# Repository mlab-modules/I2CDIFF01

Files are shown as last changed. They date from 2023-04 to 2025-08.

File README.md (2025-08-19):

# I2CDIFF01 - Differential I²C Transceiver

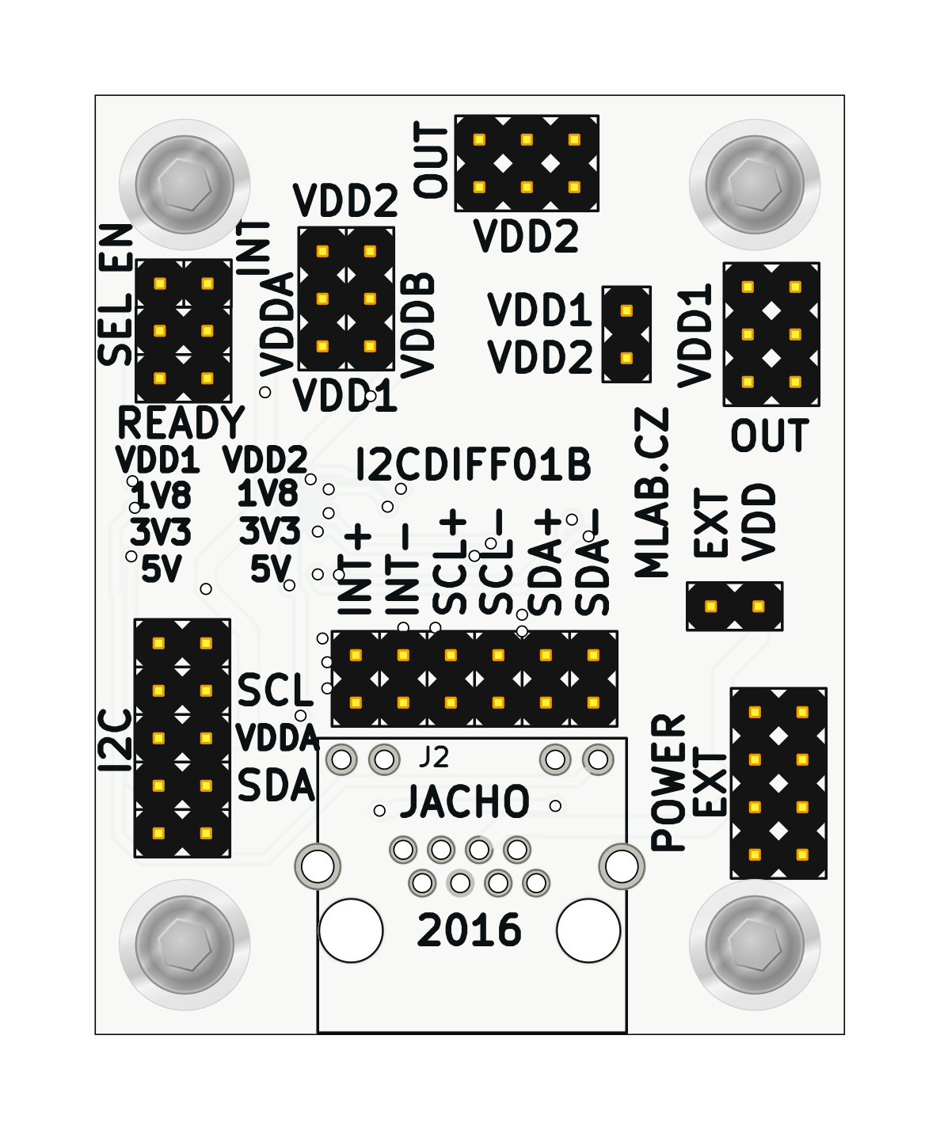
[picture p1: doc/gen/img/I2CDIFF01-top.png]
I2CDIFF01B


Allows long-range I²C communication in harsh environments. In addition to I²C data transfer, the module supports bidirectional interrupt signaling over the same cable.

## Features

* Converts standard I²C signals to differential I²C for robust transmission
* Supports interrupt signal transmission
* Uses PCA9616 buffer for differential I²C communication
* Enables power transmission over RJ45 cable
* Configurable voltage levels using onboard jumpers
* Power regulation with onboard voltage regulators
* RJ45 (Ethernet) cable for differential connection (UTP cable compatible)

## Technical Specifications

| Parameter | Value |
| --- | --- |
| Supply Voltage | Up to 15 V |
| Communication  | I²C, Differential I²C |
| Main IC | PCA9616 |
| Dimensions | 40.1 × 50.3 × 16 mm |

## Power and Voltage Configuration

* **VDDA**: Voltage for single-ended I²C side (selectable 3.3 V or 5 V by jumper; replace regulator for other voltages)
* **VDDB**: Voltage for differential I²C side (recommended 5 V)
* Power is supplied via the RJ45 cable; only one module in the chain should provide power
* Optional jumper on EXT-VDD allows routing of input voltage to internal regulator if below 15 V

## Connector Use

* **RJ45 connector** used for differential I²C transmission and power
* Do not connect the RJ45 cable to standard Ethernet equipment

## Jumpers and Configuration

* Jumpers available to select voltage sources (VDD1 or VDD2) for VDDA and VDDB
* Recommended not to use the SEL jumper when VDDA > 2.2 V
* Voltage levels indicated on PCB; use permanent marker to label used levels

## Typical Use Cases

* Extending I²C bus over longer distances
* Connecting devices across electrically noisy environments
* Applications requiring shared interrupt signaling across modules

## Notes

* Ensure proper termination of differential pairs per PCA9616 datasheet
* Verify jumper settings and supply voltages before powering the module
* Do not mix power sources across RJ45-connected modules

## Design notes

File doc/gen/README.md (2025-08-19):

# PCB

Board size: 40.13x50.29 mm (1.58x1.98 inches)

- This is the size of the rectangle that contains the board
- Thickness: 1.6 mm (63 mils)
- Material: FR4
- Finish: HAL
- Layers: 2
- Copper thickness: 35 µm

Solder mask: TOP / BOTTOM

- Color: Green

Silk screen: TOP / BOTTOM

- Color: White

# Important sizes

Clearance: 0.2 mm (8 mils)

Track width: 0.25 mm (10 mils)

- By design rules: 0.2 mm (8 mils)

Drill: 0.6 mm (24 mils)

- Vias: 0.6 mm (24 mils) [Design: 0.4 mm (16 mils)]
- Pads: 1.0 mm (39 mils)
- The above values are real drill sizes, they add 0.1 mm (4 mils) to plated holes (PTH)

Via: 0.89/0.5 mm (35/20 mils)

- By design rules: 0.7/0.3 mm (28/12 mils)
- Micro via: yes [0.3/0.1 mm (12/4 mils)]
- Buried/blind via: yes
- Total: 29 (thru: 29 buried/blind: 0 micro: 0)

Outer Annular Ring: 0.13 mm (5 mils)

- By design rules: 0.13 mm (5 mils)

Eurocircuits class: 6A
- Using min drill 0.6 mm for an OAR of 0.13 mm

# General stats

Components count: (SMD/THT)

- Top: 0/27 (THT)
- Bottom: 29/0 (SMD)

Defined tracks:

- 0.25 mm (10 mils)
- 0.3 mm (12 mils)
- 0.4 mm (16 mils)
- 0.5 mm (20 mils)
- 0.6 mm (24 mils)
- 0.7 mm (28 mils)
- 0.8 mm (31 mils)
- 0.9 mm (35 mils)

Used tracks:

- 0.25 mm (10 mils) (8) defined: yes
- 0.3 mm (12 mils) (180) defined: yes
- 0.4 mm (16 mils) (56) defined: yes
- 0.5 mm (20 mils) (63) defined: yes
- 0.6 mm (24 mils) (9) defined: yes
- 0.9 mm (35 mils) (84) defined: yes

Defined vias:

Used vias:

- 0.89/0.5 mm (35/20 mils) (Count: 29, Aspect: 1.8 A) defined: no

Holes (excluding vias):

- 0.89 mm (35 mils) (58)
- 0.93 mm (37 mils) (12)
- 1.65 mm (65 mils) (2)
- 3.0 mm (118 mils) (4)
- 3.3 mm (130 mils) (2)

Oval holes:

Drill tools (including vias and computing adjusts and rounding):

- 0.6 mm (24 mils) (29)
- 1.0 mm (39 mils) (58)
- 1.05 mm (41 mils) (12)
- 1.75 mm (69 mils) (2)
- 3.1 mm (122 mils) (4)
- 3.3 mm (130 mils) (2)

Solder paste stats:

Using a paste with 87.75 % alloy, that has an specific gravity for the alloy of 7.4 g/cm³
and 1.0 g/cm³ for the flux. This paste has an specific gravity of  4.15 g/cm³.

The stencil thickness is  0.12 mm.

| Side | Pads with paste | Area [mm²] | Paste [g] |
|---|---|---|---|
| Total  | 82 | 118.29 | 0.59 |

Note: this is just an approximation to the theoretical value. Margins of the solder mask and waste aren't computed.

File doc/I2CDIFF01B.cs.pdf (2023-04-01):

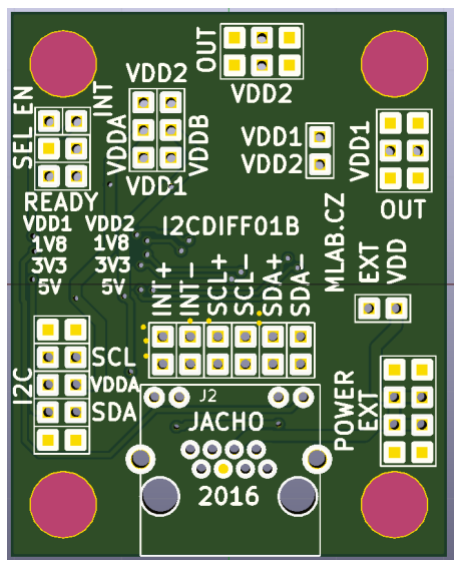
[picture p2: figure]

I2CDIFF01B / 2018-11-05 / jacho / http://www.mlab.cz | 1 / 5
I2CDIFF01B | MLAB

# I2CDIFF01B – převodník I2C / diferenční I2C

Jan Chroust, Jakub Kákona

Převodník umožňuje přenášet I2C signál na delší vzdálenosti i v nepříznivých podmínkách. Tento vzdálený přenos je možný díky převodu klasického I2C na diferenční. Modul umožňuje obousměrné přenášení interruptu. Propojení na straně diferenčního signálu je pomocí kabelu s RJ45 (ethernetový kabel). Modul umožňuje přenášení napájecího napětí mezi dvojicí modulů. Díky dvojici stabilizátorů je možné napětí upravit na běžně používané napěťové

úrovně.

# 1. Technické parametry

Parametr | Hodnota | Poznámka
Napájení | Max 15 V
Rozhraní | I2C, diferenční I2C
Integrovaný obvod | PCA9616
Rozměr | 40,1 x 50,3 x 16 mm

I2CDIFF01B | MLAB

# 2. Popis konstrukce

## 2.1. Úvodem

Jedná se o převodník s mnoha možnostmi využití. Převodníky je možné vložit mezi jakékoliv zařízení komunikující na I2C a tím umožnit prodloužení vzdálenosti mezi zařízeními. Výhodou modulu je, že není potřeba žádné změny kódu v zařízení.

Propojování převodníků je možné realizovat pomocí standardního ethernetového kabelu s konektorem RJ45. Struktura propojení může být různá dle požadavku aplikace (hvězdicová topologie, stromová topologie…).

I když modul obsahuje konektor RJ45, tak není možné tento modul zapojit do jakýchkoliv jiných zařízení, krom tohoto modulu!!!

Napájení modulu je vedeno v datovém kabelu. Modul je možné napájet maximálním napětím 15 V. Napětí je omezeno stabilizátory. Pokud by bylo potřeba přenášet kabelem napětí větší, tak je potřeba od tohoto napětí odpojit napájení modulu. Následně je možné napětí externím měničem snížit a zpátky přivést pro napájení modulu.

Pokud je napájení po kabelu menší než 15 V je možné pomocí jumperu na EXT-VDD přivést toto napětí na vstup stabilizátoru.

Modul umožňuje pomocí jumperů volbu napěťové úrovně pro signály na obou stranách. Na straně diferenčního I2C je doporučena úroveň 5V (vyšší napětí obvod neumožňuje). Na straně I2C je možné si standardně volit mezi 3,3 V nebo 5 V. Při potřebě nižšího napětí je potřeba modul osadit jiným stabilizátorem.

VDDA je napětí pro stranu I2C. VDDB je napětí pro diferenční I2C.

Napětí, které je připojeno na VDDA, nebo VDDB se volí pomocí jumperů. Napětí je možné volit mezi VDD1 a VDD2. Tyto hodnoty jsou dány osazenými stabilizátory. Aktuální napětí je vždy zobrazeno na plošném spoji. Ostatní úrovně napětí se zaškrtávají nesmazatelným fixem.

Pokud je VDDA zvoleno větší než 2,2 V, tak není potřeba umísťovat na pozici SEL jumper.

Napájecí hřebínek POWER EXT je propojen s napájecím párem vodičů na konektoru RJ45. Na jedné straně proto tento hřebínek slouží pro přivedení napětí, které je přes kabel přivedeno na konektor POWER EXT druhého převodníku, kde tento hřebínek slouží jako výstupní. Není proto možné připojit na tyto konektory na obou stranách napájení a propojit je mezi sebou ethernetovým kabelem. Při propojení více převodníků mezi sebou může být přivedeno napětí pouze na jeden hřebínek na ostatních převodníkách se tento hřebínek chová jako výstupní.

I2CDIFF01B | MLAB

# 3. Zapojení modulu

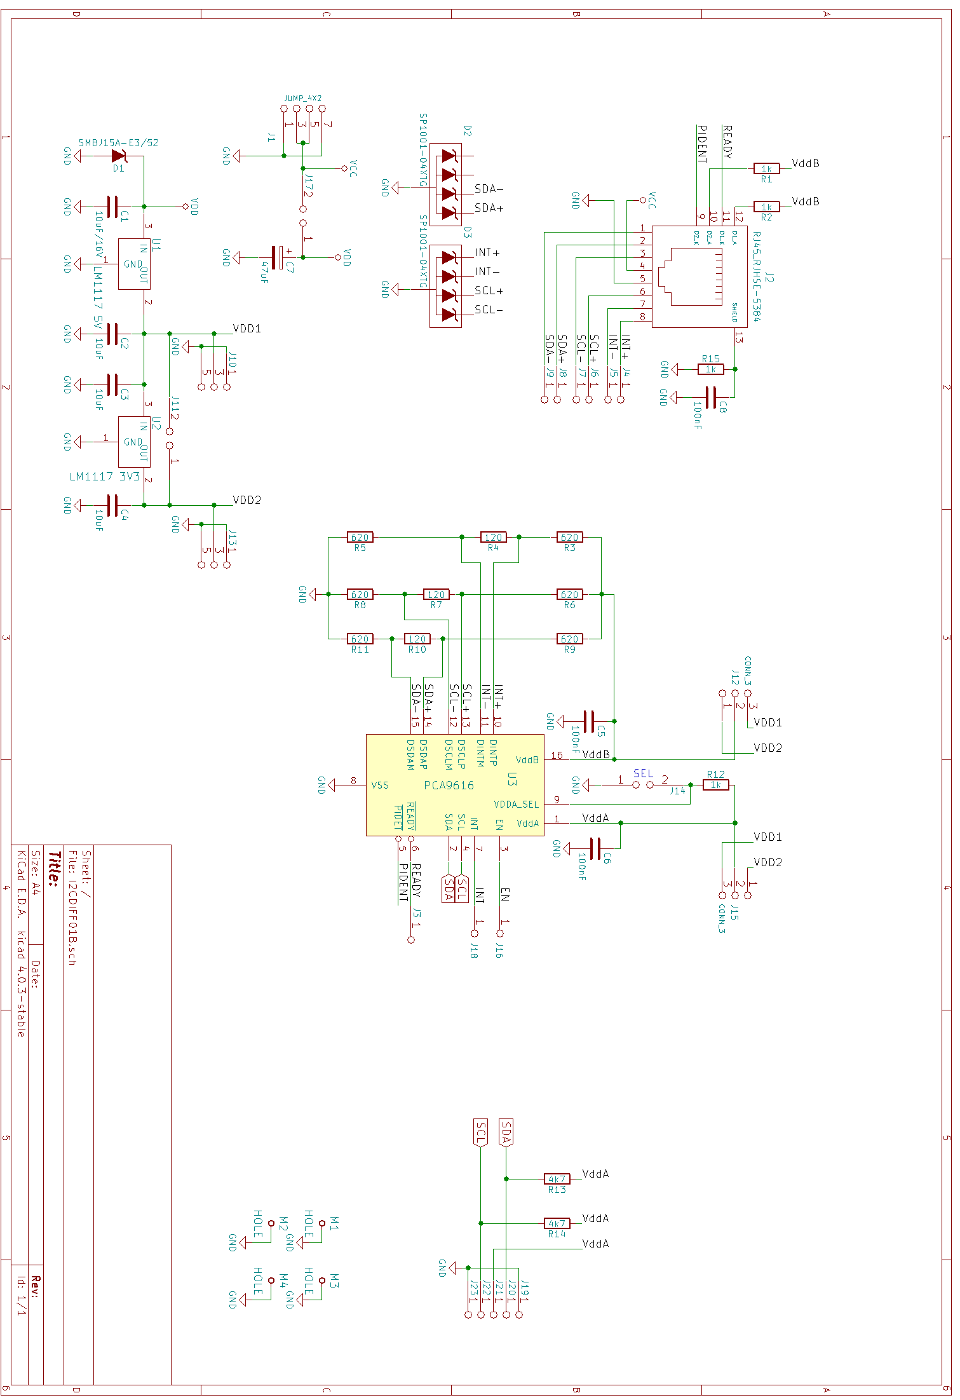
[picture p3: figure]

I2CDIFF01B | MLAB

# 4. Osazení a oživení

## 4.1. Osazení

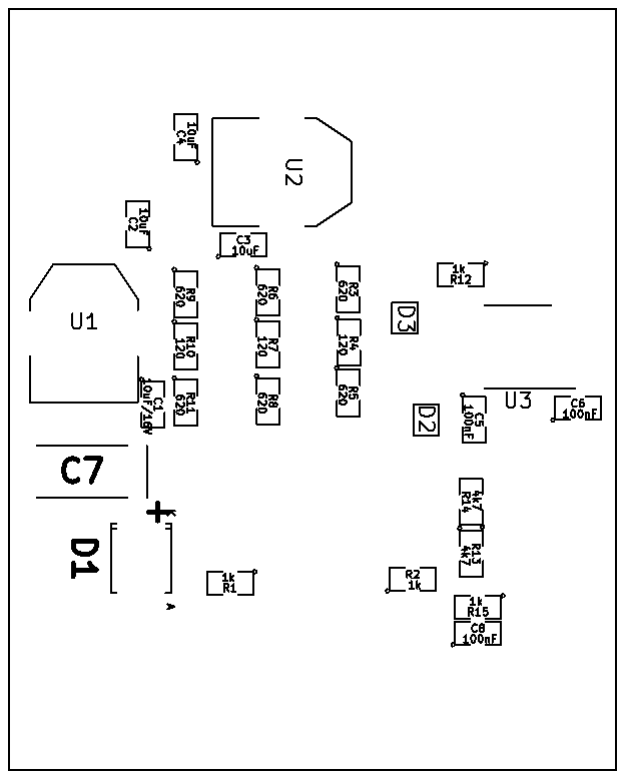
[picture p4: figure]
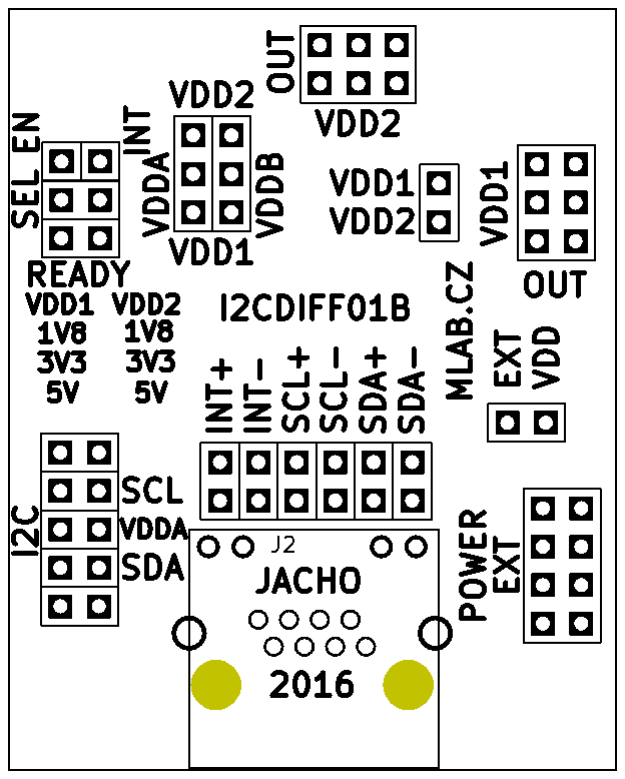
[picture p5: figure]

I2CDIFF01B | MLAB

## 4.2. Seznam součástek

Označení | Typ | Pouzdro | Počet
J2 | RJ45_RJHSE-5384 | RJHSE-5384(RJ45) | 1
J1 | JUMP_4X2 | Straight_2x04 | 1
C1 | 10uF/16V | SMD-0805 | 1
C2,C3,C4 | 10uF | SMD-0805 | 3
C6,C5 | 100nF | SMD-0805 | 2
J4,J5,J6,J7,J8,J9 | JUMP_2x1 | Straight_2x01 | 6
J10,J13 | JUMP_3X2 | Straight_2x03 | 2
J11,J14,J17 | JUMP2_2x1 | Straight_2x01 | 3
J12,J15 | CONN_3 | Straight_1x03 | 2
J19,J20,J21,J22,J23,J3 | JUMP_2x1 | Straight_1x02 | 6
M1,M2,M3,M4 | HOLE | MountingHole_3mm | 4
R1,R2,R12 | 1k | SMD-0805 | 3
R3,R5,R6,R8,R9,R11 | 620 | SMD-0805 | 6
R4,R7,R10 | 120 | SMD-0805 | 3
R14,R13 | 4k7 | SMD-0805 | 2
U1 | LM1117 5V | SOT-223 | 1
U2 | LM1117 3V3 | SOT-223 | 1
U3 | PCA9616 | TSSOP-16_4.4x5mm_Pitch0.65mm | 1
C7 | 47uF | TantalC_SizeC_Reflow | 1
D2,D3 | SP1001-04XTG | SOT-553 | 2
C8 | 100nF | SMD-0805 | 1
R15 | 1k | SMD-0805 | 1
J18,J16 | CONN1_1 | Straight_1x01 | 2
D1 | SMBJ15A-E3/52 | Diode-SMB_Standard | 1

Jumper: VDDA-VDD2, VDDB-VDD1, EXT-VDD

Začernit nevyužitá napětí stabilizátorů

## 4.3. Oživení

Zkontrolovat zkraty na napájení

Ověřit úrovně napětí za stabilizátory

Postup pro ověření funkčnosti:
-propojit dva I2CDIFF pomocí ethernetového kabelu
-k jednomu I2CDIFF připojit I2C senzor, který má knihovnu v pyMLAB
-ke druhému I2CDIFF připojit převodník USBI2C
-jeden I2CDIFF je potřeba napájet 12V
-následně stačí připojit USB kabel do počítače vyvedený z USBI2C a spustit program v pyMLABu.

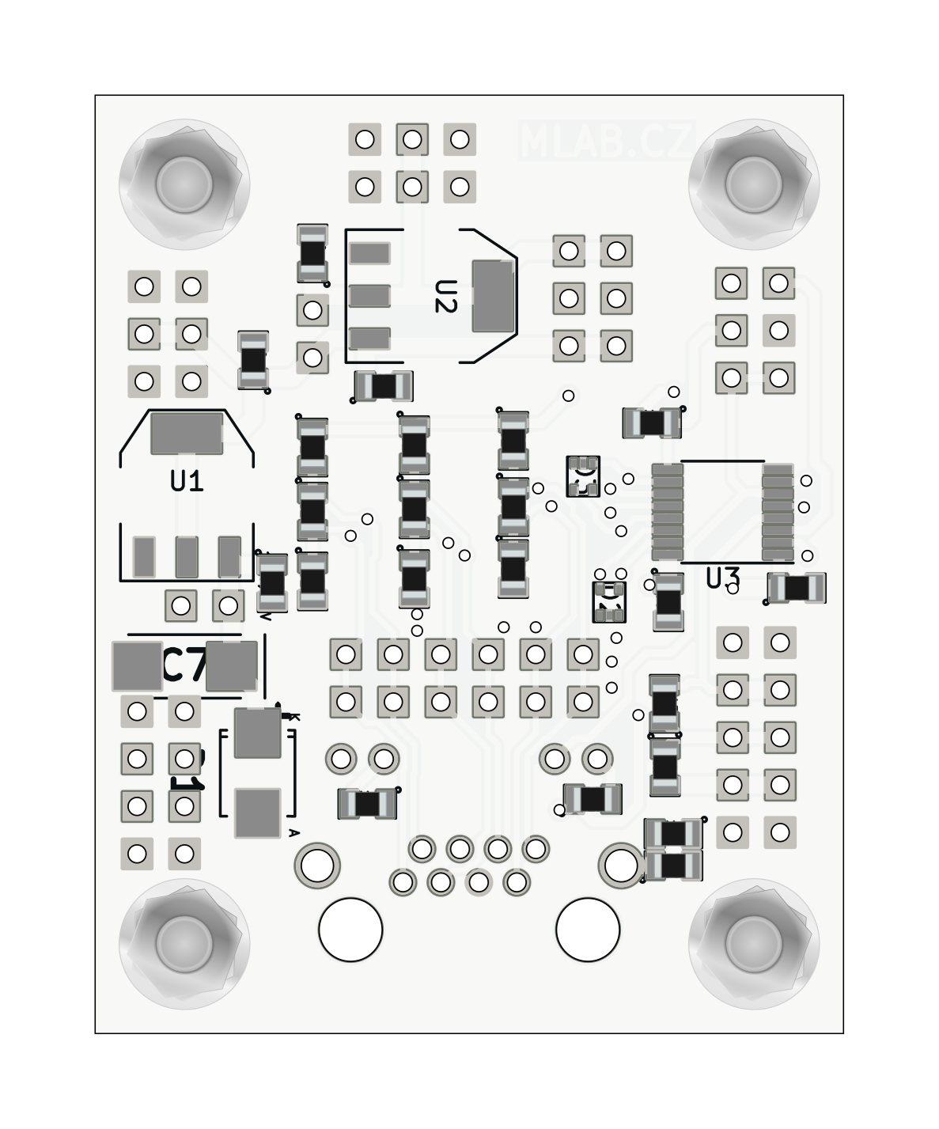
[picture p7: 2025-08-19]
doc/gen/img/I2CDIFF01-bottom.png

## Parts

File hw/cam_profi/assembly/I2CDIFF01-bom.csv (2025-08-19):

Component | Description | Part | References | Value | Footprint | Quantity Per PCB | Datasheet
1 |  | C_9 | C5 | 100nF | SMD-0805 | 1
2 |  | C_8 | C6 | 100nF | SMD-0805 | 1
3 |  | C_10 | C8 | 100nF | SMD-0805 | 1
4 |  | C_12 | C2 | 10uF | SMD-0805 | 1
5 |  | C_13 | C3 | 10uF | SMD-0805 | 1
6 |  | C_14 | C4 | 10uF | SMD-0805 | 1
7 |  | CP_2 | C7 | 47uF | TantalC_SizeC_Reflow | 1
8 |  | C_11 | C1 | 10uF/16V | SMD-0805 | 1
9 |  | D_ZENER_2 | D1 | SMBJ15A-E3/52 | Diode-SMB_Standard | 1
10 |  | D_4xZENER_3 | D2 | SP1001-04XTG | SOT-553 | 1
11 |  | D_4xZENER_4 | D3 | SP1001-04XTG | SOT-553 | 1
12 |  | CONN1_1_3 | J16 | CONN1_1 | Straight_1x01 | 1
13 |  | CONN1_1_4 | J18 | CONN1_1 | Straight_1x01 | 1
14 |  | CONN_3_4 | J12 | CONN_3 | Straight_1x03 | 1
15 |  | CONN_3_3 | J15 | CONN_3 | Straight_1x03 | 1
16 |  | JUMP2_2x1_6 | J11 | JUMP2_2x1 | Straight_2x01 | 1
17 |  | JUMP2_2x1_4 | J14 | JUMP2_2x1 | Straight_2x01 | 1
18 |  | JUMP2_2x1_5 | J17 | JUMP2_2x1 | Straight_2x01 | 1
19 |  | JUMP_2x1_17 | J19 | JUMP_2x1 | Straight_1x02 | 1
20 |  | JUMP_2x1_15 | J20 | JUMP_2x1 | Straight_1x02 | 1
21 |  | JUMP_2x1_16 | J21 | JUMP_2x1 | Straight_1x02 | 1
22 |  | JUMP_2x1_18 | J22 | JUMP_2x1 | Straight_1x02 | 1
23 |  | JUMP_2x1_14 | J23 | JUMP_2x1 | Straight_1x02 | 1
24 |  | JUMP_2x1_13 | J3 | JUMP_2x1 | Straight_1x02 | 1
25 |  | JUMP_2x1_24 | J4 | JUMP_2x1 | Straight_2x01 | 1
26 |  | JUMP_2x1_19 | J5 | JUMP_2x1 | Straight_2x01 | 1
27 |  | JUMP_2x1_20 | J6 | JUMP_2x1 | Straight_2x01 | 1
28 |  | JUMP_2x1_21 | J7 | JUMP_2x1 | Straight_2x01 | 1
29 |  | JUMP_2x1_22 | J8 | JUMP_2x1 | Straight_2x01 | 1
30 |  | JUMP_2x1_23 | J9 | JUMP_2x1 | Straight_2x01 | 1
31 |  | JUMP_3X2_4 | J10 | JUMP_3X2 | Straight_2x03 | 1
32 |  | JUMP_3X2_3 | J13 | JUMP_3X2 | Straight_2x03 | 1
33 |  | JUMP_4X2_2 | J1 | JUMP_4X2 | Straight_2x04 | 1
34 |  | RJ45_RJHSE-5384_2 | J2 | RJ45_RJHSE-5384 | RJHSE-5384(RJ45) | 1
35 |  | R_24 | R10 | 120 | SMD-0805 | 1
36 |  | R_26 | R4 | 120 | SMD-0805 | 1
37 |  | R_21 | R7 | 120 | SMD-0805 | 1
38 |  | R_23 | R11 | 620 | SMD-0805 | 1
39 |  | R_27 | R3 | 620 | SMD-0805 | 1
40 |  | R_25 | R5 | 620 | SMD-0805 | 1
41 |  | R_18 | R6 | 620 | SMD-0805 | 1
42 |  | R_22 | R8 | 620 | SMD-0805 | 1
43 |  | R_17 | R9 | 620 | SMD-0805 | 1
44 |  | R_29 | R1 | 1k | SMD-0805 | 1
45 |  | R_16 | R12 | 1k | SMD-0805 | 1
46 |  | R_30 | R15 | 1k | SMD-0805 | 1
47 |  | R_28 | R2 | 1k | SMD-0805 | 1
48 |  | R_19 | R13 | 4k7 | SMD-0805 | 1
49 |  | R_20 | R14 | 4k7 | SMD-0805 | 1
50 |  | LM1117_4 | U2 | LM1117 3V3 | SOT-223 | 1
51 |  | LM1117_3 | U1 | LM1117 5V | SOT-223 | 1
52 |  | PCA9616_2 | U3 | PCA9616 | TSSOP-16_4.4x5mm_Pitch0.65mm | 1

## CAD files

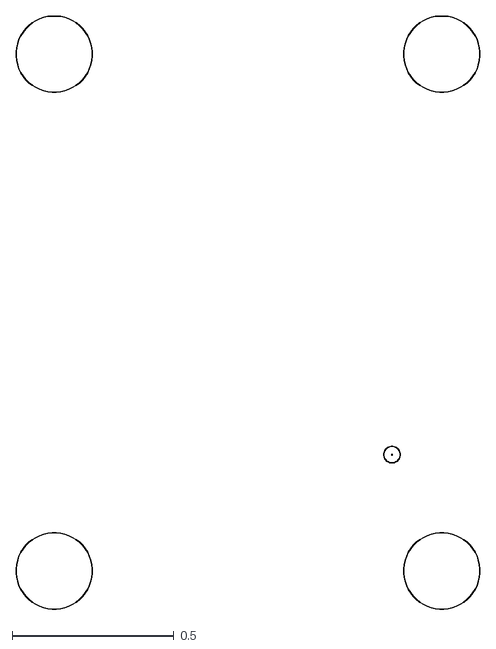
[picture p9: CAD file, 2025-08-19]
doc/gen/dxf/I2CDIFF01-B_Adhesive.dxf
1.44 x 1.84

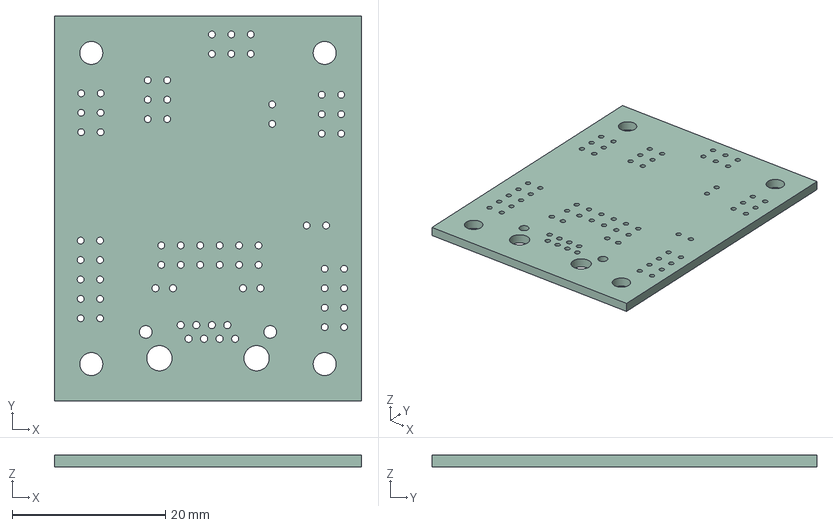
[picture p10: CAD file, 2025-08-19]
doc/gen/I2CDIFF01.step
40.1 x 50.3 x 1.51 mm

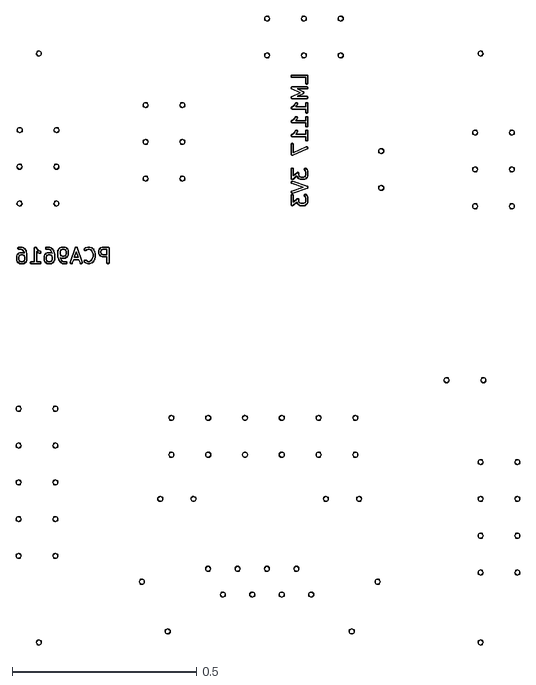
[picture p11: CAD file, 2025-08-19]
doc/gen/dxf/I2CDIFF01-B_Fab.dxf
1.37 x 1.71

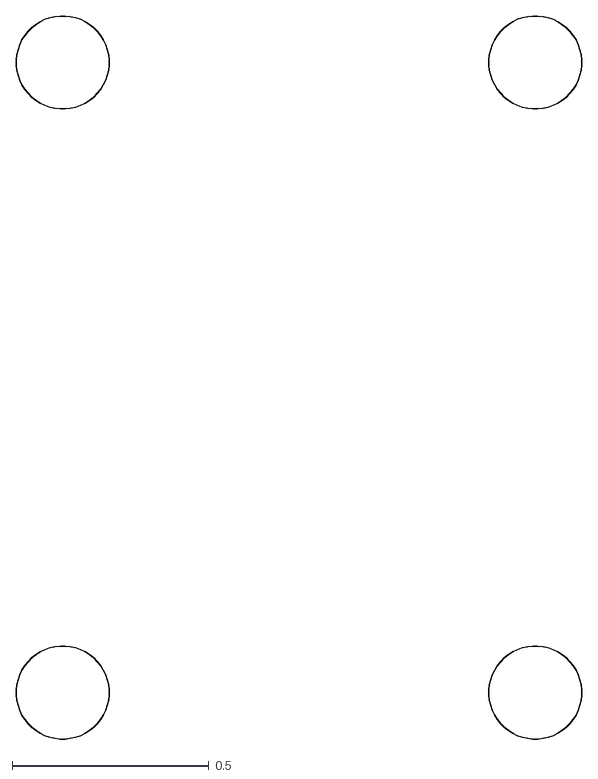
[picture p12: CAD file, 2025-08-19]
doc/gen/dxf/I2CDIFF01-F_Adhesive.dxf
1.44 x 1.84

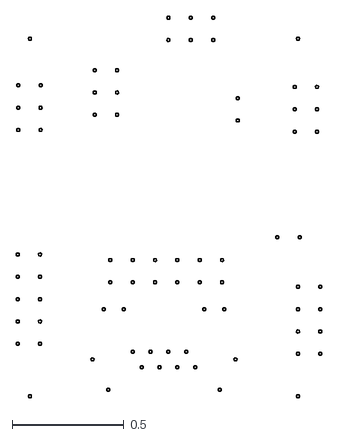
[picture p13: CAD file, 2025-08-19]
doc/gen/dxf/I2CDIFF01-User_Eco1.dxf
1.37 x 1.71

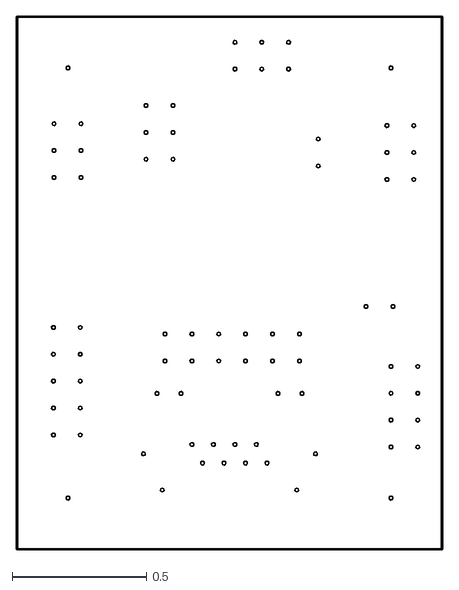
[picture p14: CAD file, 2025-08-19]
doc/gen/dxf/I2CDIFF01-Edge_Cuts.dxf
1.58 x 1.98

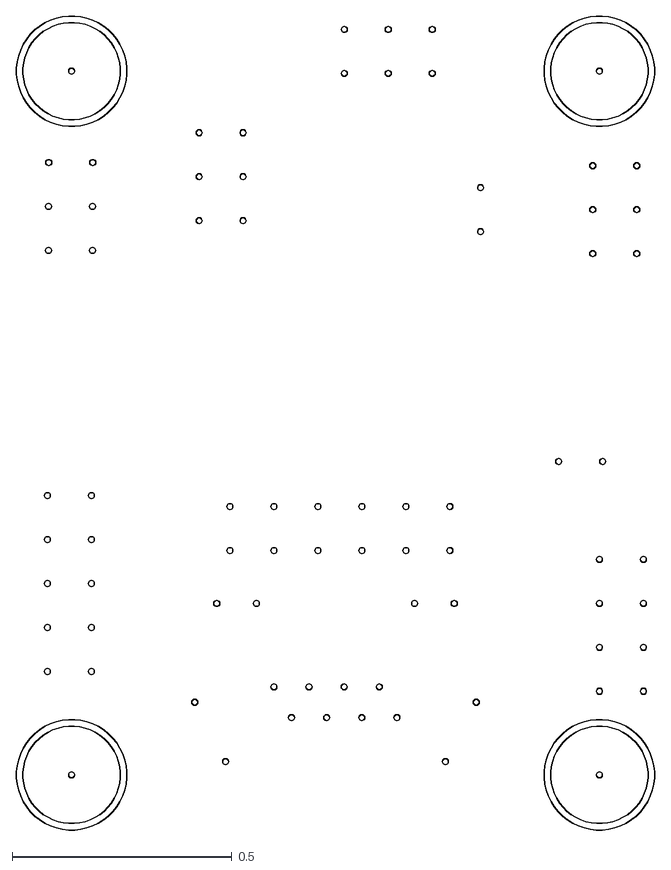
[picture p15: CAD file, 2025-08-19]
doc/gen/dxf/I2CDIFF01-User_Comments.dxf
1.45 x 1.85

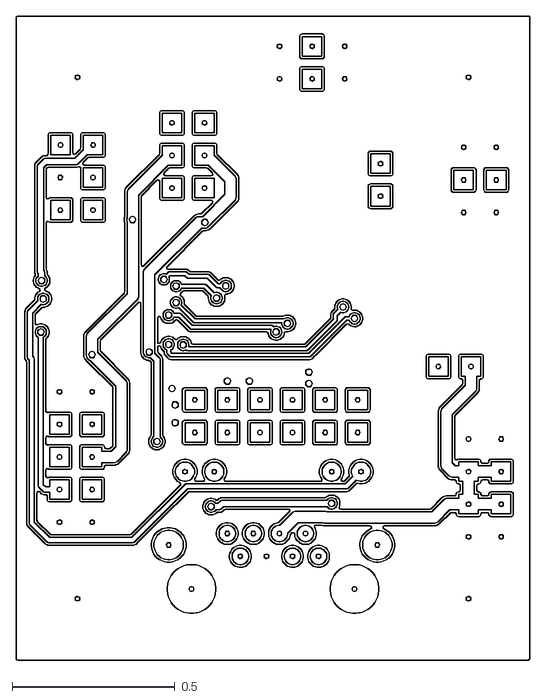
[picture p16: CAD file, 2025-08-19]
doc/gen/dxf/I2CDIFF01-F_Cu.dxf
1.58 x 1.98

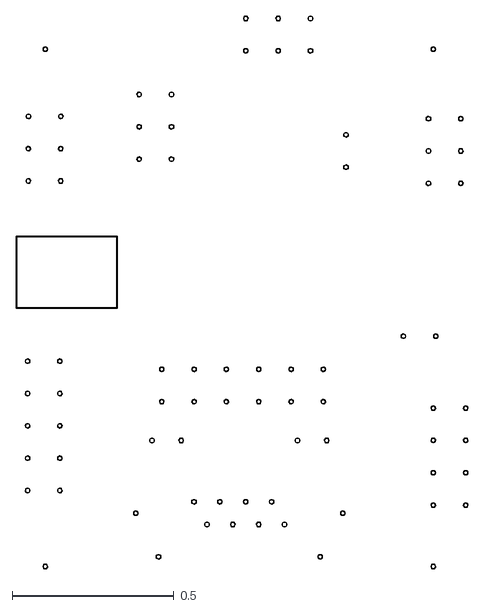
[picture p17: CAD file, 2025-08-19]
doc/gen/dxf/I2CDIFF01-B_Courtyard.dxf
1.40 x 1.71

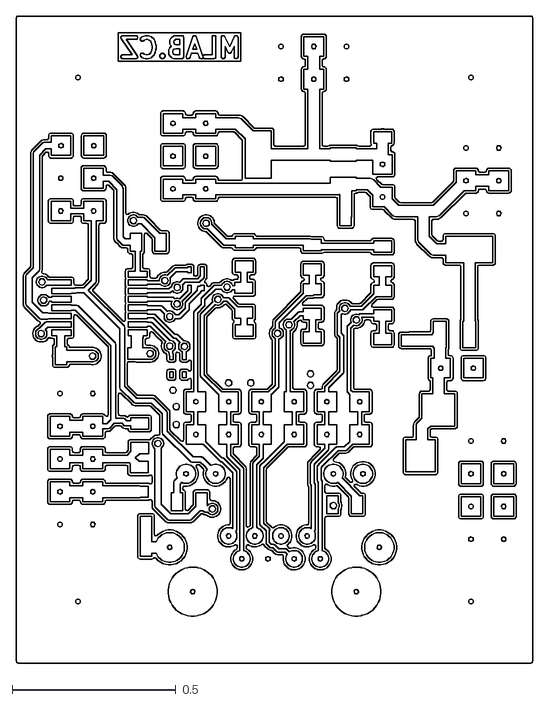
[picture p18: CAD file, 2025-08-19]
doc/gen/dxf/I2CDIFF01-B_Cu.dxf
1.58 x 1.98

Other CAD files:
doc/gen/dxf/I2CDIFF01-B_Mask.dxf
doc/gen/dxf/I2CDIFF01-B_Paste.dxf
doc/gen/dxf/I2CDIFF01-B_Silkscreen.dxf
doc/gen/dxf/I2CDIFF01-F_Mask.dxf
doc/gen/dxf/I2CDIFF01-F_Paste.dxf
doc/gen/dxf/I2CDIFF01-F_Silkscreen.dxf

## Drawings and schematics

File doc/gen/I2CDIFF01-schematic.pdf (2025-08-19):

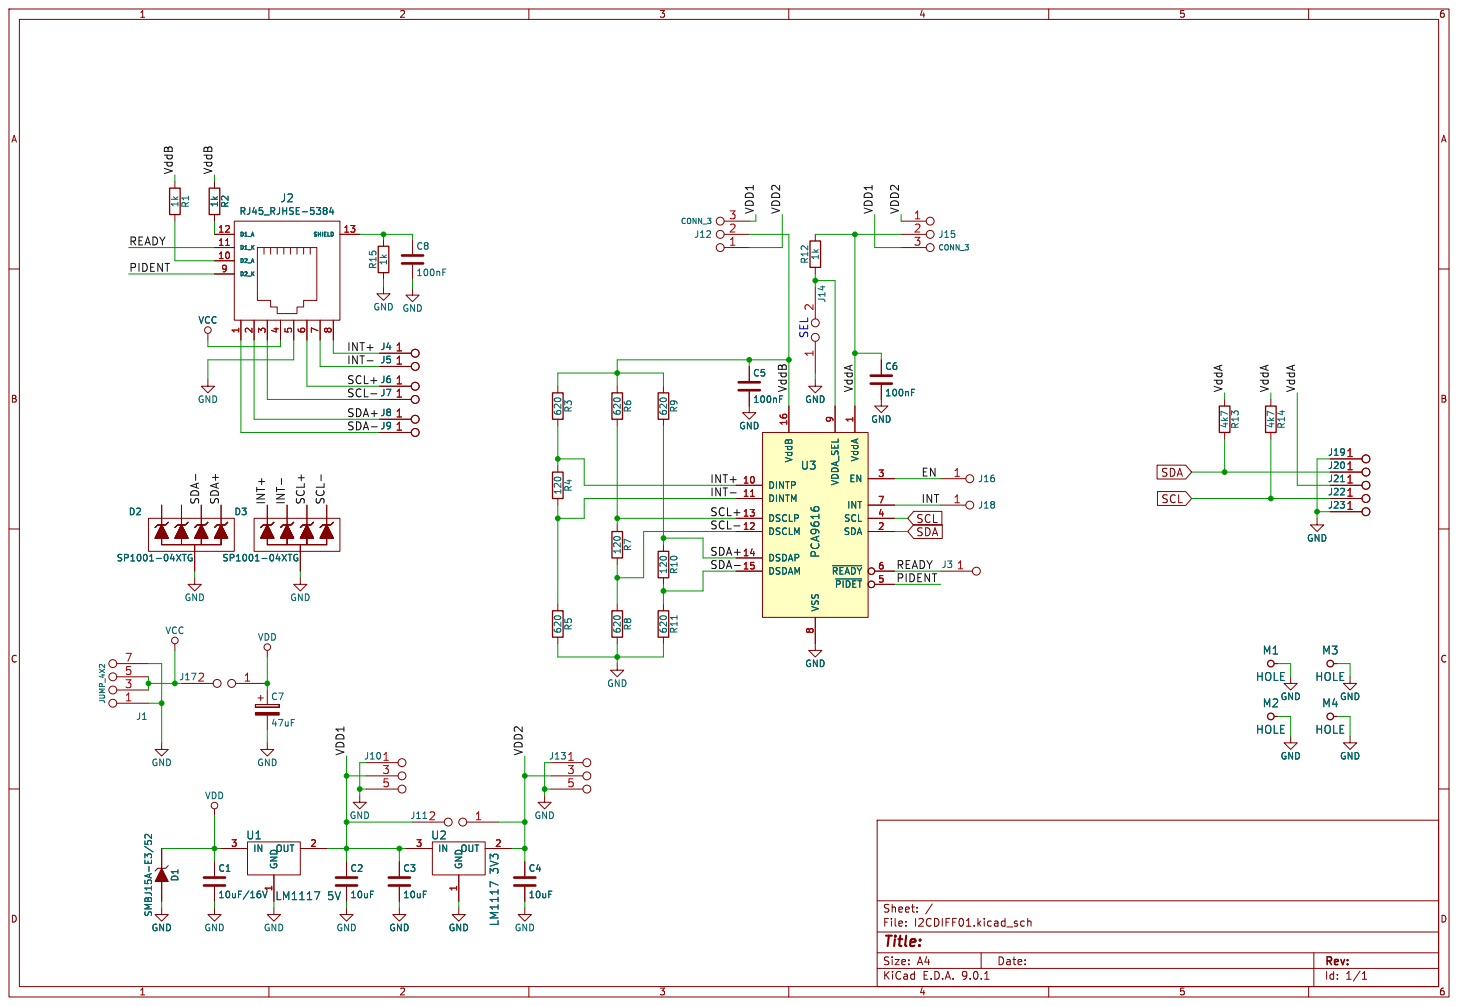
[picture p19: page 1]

Id: 1/1 Title: File: I2CDIFF01.kicad_sch Sheet: /

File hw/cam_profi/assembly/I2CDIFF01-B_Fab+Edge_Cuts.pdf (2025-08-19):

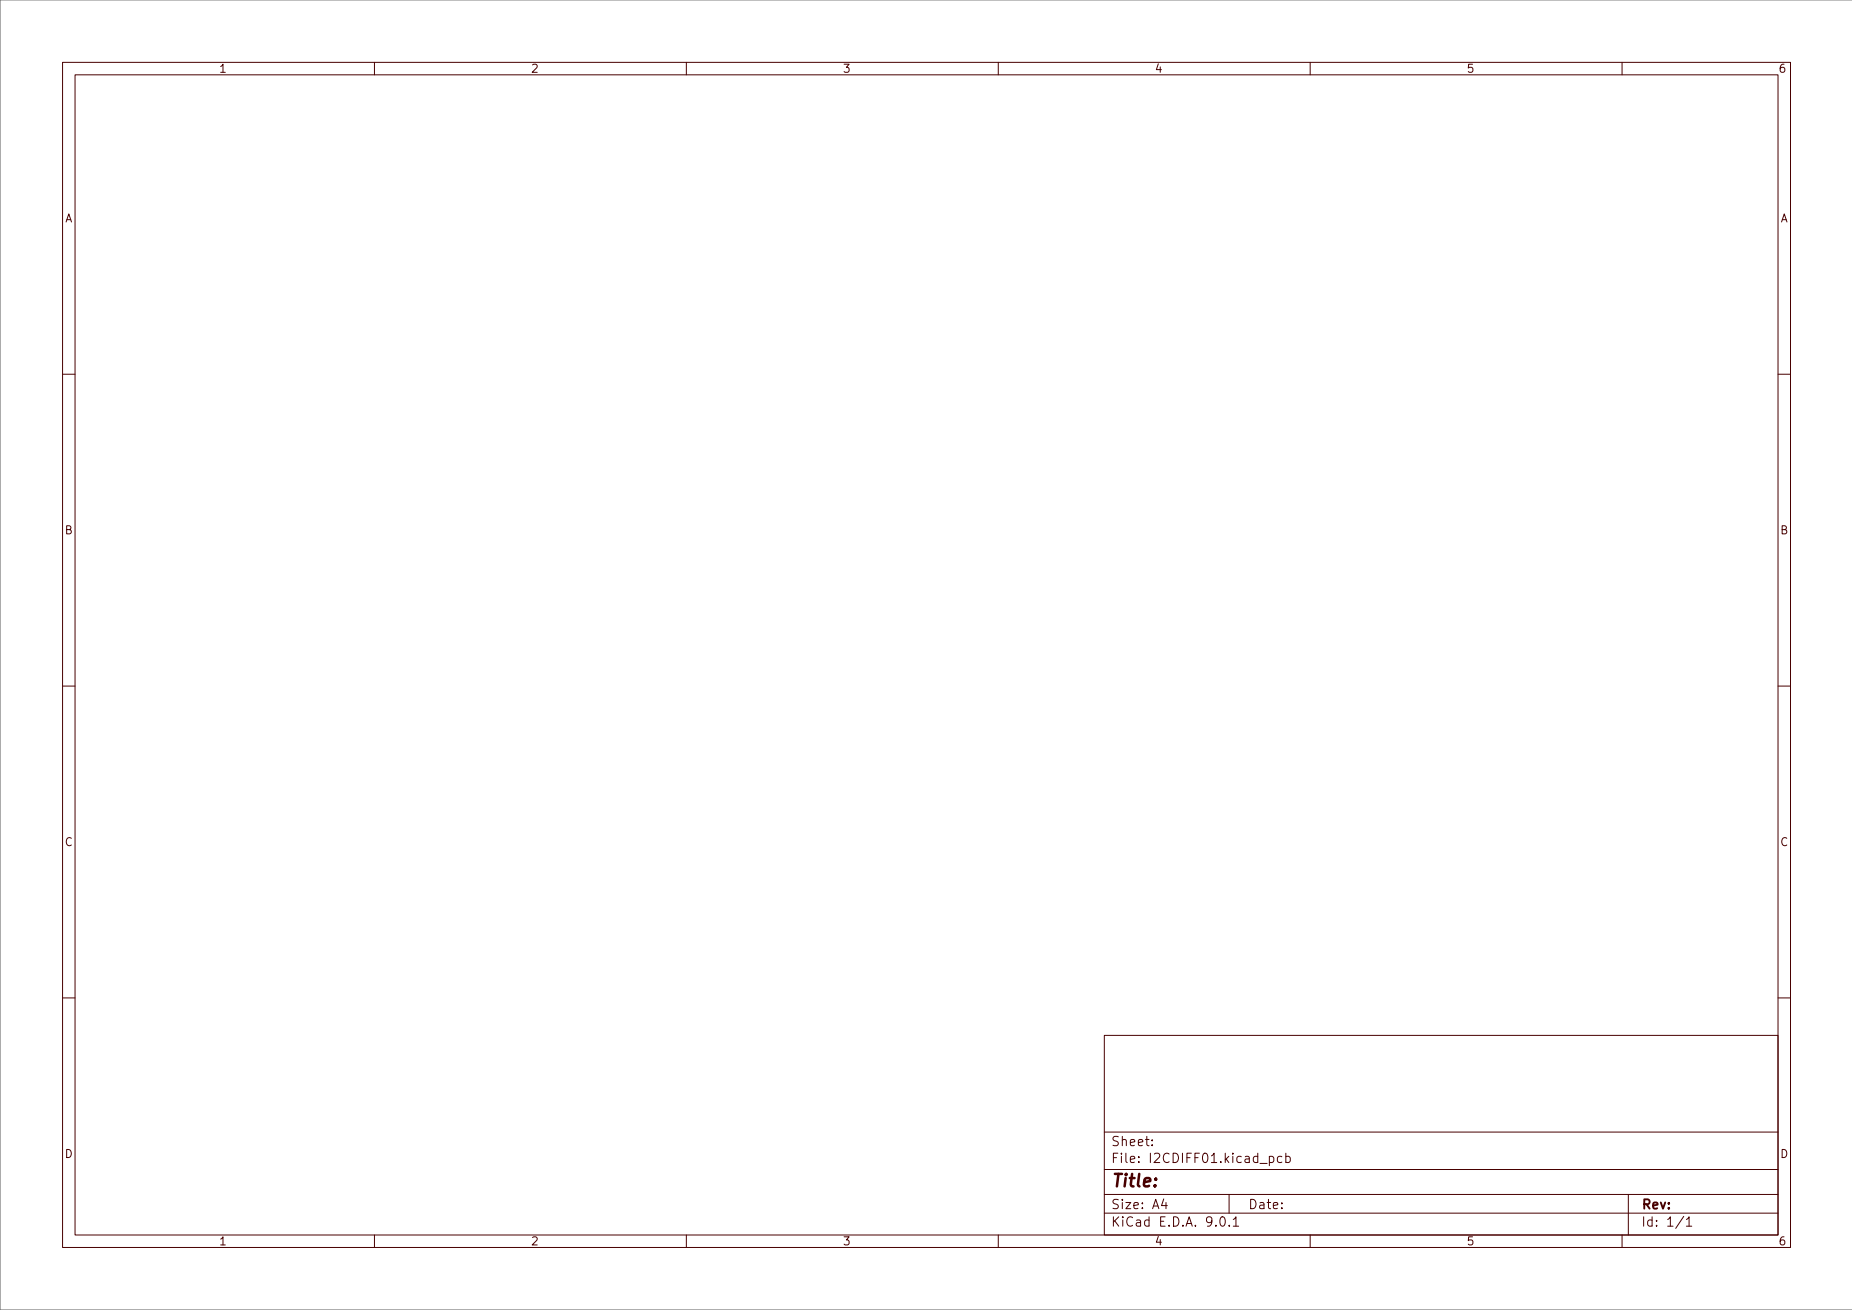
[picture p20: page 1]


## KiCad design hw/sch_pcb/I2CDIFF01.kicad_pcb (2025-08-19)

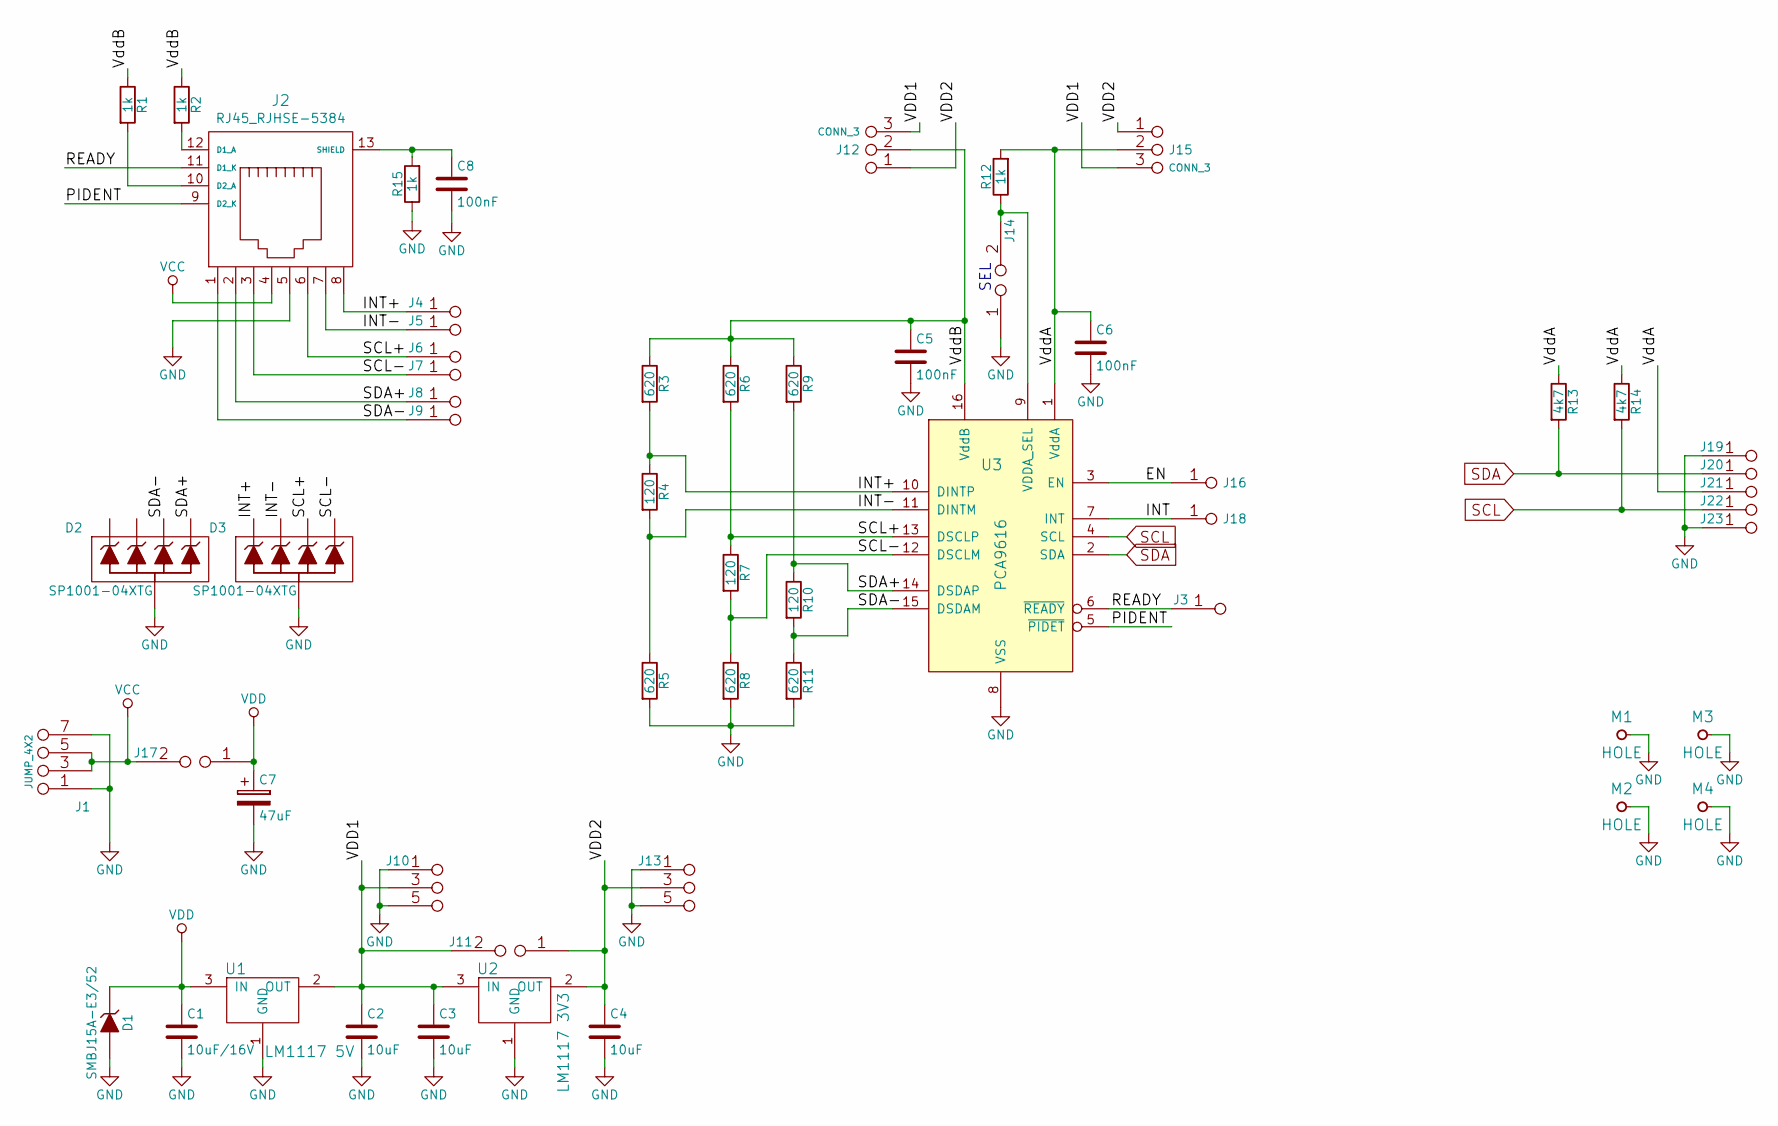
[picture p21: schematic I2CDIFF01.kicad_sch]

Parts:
C1: 10uF/16V; SMD-0805
C2, C3, C4: 10uF; SMD-0805
C5, C6, C8: 100nF; SMD-0805
C7: 47uF; TantalC_SizeC_Reflow
D1: SMBJ15A-E3/52; Diode-SMB_Standard
D2, D3: SP1001-04XTG; SOT-553
J1: JUMP_4X2; Straight_2x04
J2: RJ45_RJHSE-5384; RJHSE-5384(RJ45)
J3, J19, J20, J21, J22, J23: JUMP_2x1; Straight_1x02
J4, J5, J6, J7, J8, J9: JUMP_2x1; Straight_2x01
J10, J13: JUMP_3X2; Straight_2x03
J11, J14, J17: JUMP2_2x1; Straight_2x01
J12, J15: CONN_3; Straight_1x03
J16, J18: CONN1_1; Straight_1x01
M1, M2, M3, M4: HOLE; MountingHole_3mm
R1, R2, R12, R15: 1k; SMD-0805
R3, R5, R6, R8, R9, R11: 620; SMD-0805
R4, R7, R10: 120; SMD-0805
R13, R14: 4k7; SMD-0805
U1: LM1117 5V; SOT-223
U2: LM1117 3V3; SOT-223
U3: PCA9616; TSSOP-16_4.4x5mm_Pitch0.65mm

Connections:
/EN: J16.1, U3.3 (EN)
/INT: J18.1, U3.7 (INT)
/INT+: D3.1, J2.8, J4.1, J4.2, R3.2, R4.1, U3.10 (DINTP)
/INT-: D3.3, J2.7, J5.1, J5.2, R4.2, R5.1, U3.11 (DINTM)
/PIDENT: J2.9 (D2_K), U3.5 (~PIDET)
/READY: J2.11 (D1_K), J3.1, J3.2, U3.6 (~READY)
/SCL+: D3.4, J2.6, J6.1, J6.2, R6.2, R7.1, U3.13 (DSCLP)
/SCL-: D3.5, J2.3, J7.1, J7.2, R7.2, R8.1, U3.12 (DSCLM)
/SDA+: D2.5, J2.2, J8.1, J8.2, R9.2, R10.1, U3.14 (DSDAP)
/SDA-: D2.4, J2.1, J9.1, J9.2, R10.2, R11.1, U3.15 (DSDAM)
/VDD1: C2.1, C3.1, J10.3 (4), J10.4, J11.2, J12.3, J15.3, U1.2 (OUT), U1.4 (OUT), U2.3 (IN)
/VDD2: C4.1, J11.1, J12.1, J13.3 (4), J13.4, J15.1, U2.2 (OUT), U2.4 (OUT)
/VddA: C6.1, J15.2 (PM), J21.1, J21.2, R12.2, R13.1, R14.1, U3.1 (VddA)
/VddB: C5.1, J12.2 (PM), R1.1, R2.1, R3.1, R6.1, R9.1, U3.16 (VddB)
GND: C1.2, C2.2, C3.2, C4.2, C5.2, C6.2, C7.2, C8.2, D1.1 (A), D2.2, D3.2, J1.1 (2), J1.2, J1.7 (8), J1.8, J2.5, J10.1 (2), J10.2, J10.5 (6), J10.6, J13.1 (2), J13.2, J13.5 (6), J13.6, J14.1, J19.1, J19.2, J23.1, J23.2, M1.1, M2.1, M3.1, M4.1, R5.2, R8.2, R11.2, R15.1, U1.1 (GND), U2.1 (GND), U3.8 (VSS)
unnamed: C8.1, J2.13 (SHIELD), R15.2
unnamed: J2.10 (D2_A), R1.2
unnamed: J2.12 (D1_A), R2.2
unnamed: J14.2, R12.1, U3.9 (VDDA_SEL)
SCL: J22.1, J22.2, R14.2, U3.4 (SCL)
SDA: J20.1, J20.2, R13.2, U3.2 (SDA)
VCC: J1.3 (4), J1.4, J1.5, J1.6 (5), J2.4, J17.2
VDD: C1.1, C7.1, D1.2 (K), J17.1, U1.3 (IN)

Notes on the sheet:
SEL

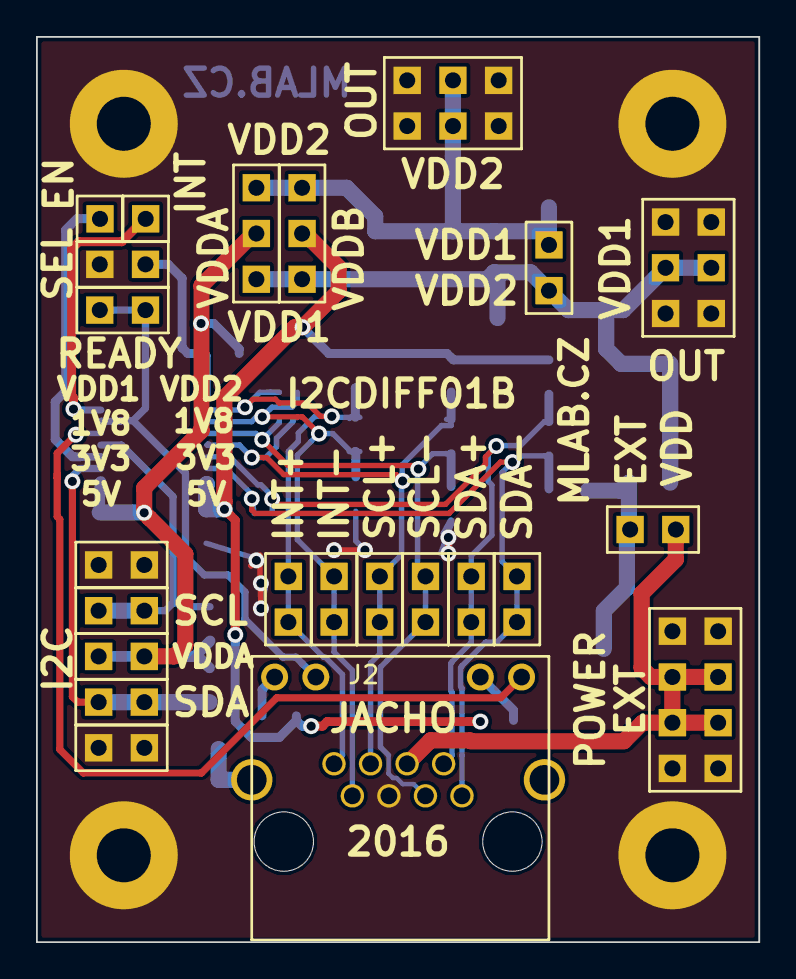
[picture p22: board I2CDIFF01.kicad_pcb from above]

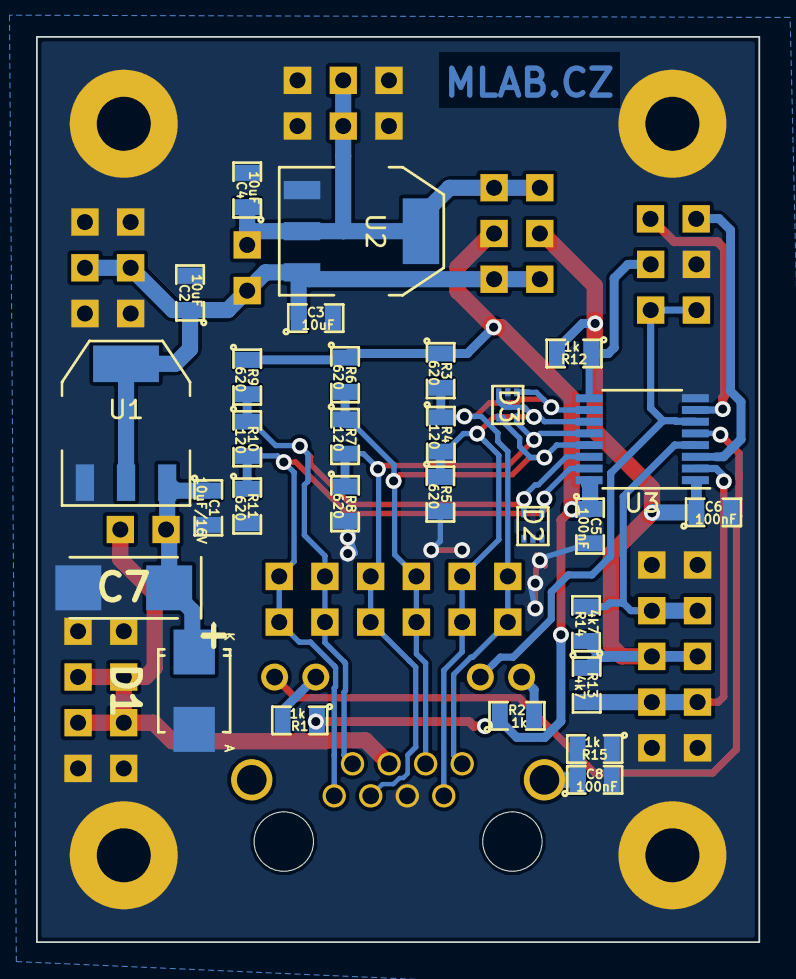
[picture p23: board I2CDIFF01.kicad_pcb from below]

Board: 2 copper layers, 40.1 x 50.3 mm, 56 parts (29 on the bottom side), 23 nets.

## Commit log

2023-04-01 Adding force option to enable splitting in not fresh copy of Modules repository.
    [I2CDIFF01B-B.Cu.gbr, I2CDIFF01B-B.Mask.gbr, I2CDIFF01B-Edge.Cuts.gbr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]
2025-08-19 Update workflow and KiCAD project to v 9.
    [I2CDIFF01B.kicad_pcb, I2CDIFF01B.kicad_sch]
2025-08-19 Cleanup repository and KiCAD project.
    [I2CDIFF01.kicad_pcb, I2CDIFF01.kicad_sch, I2CDIFF01B.sch]
2025-08-19 Update actions products
    [I2CDIFF01-B_Adhesive.dxf, I2CDIFF01-B_Courtyard.dxf, I2CDIFF01-B_Cu.dxf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]
